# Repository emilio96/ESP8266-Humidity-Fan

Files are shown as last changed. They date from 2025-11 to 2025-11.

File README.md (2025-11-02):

# ESP8266 Smart Fan Controller for Humidity Control

This project is an intelligent fan controller designed to manage air circulation in areas with high humidity, such as behind wardrobes or in damp rooms.

It operates by monitoring ambient temperature and humidity with an **AHTx0 sensor**. Based on these readings, it intelligently controls the speed of a 4-pin PWM computer fan (specifically tested with an ARCTIC F12 PWM) to ensure continuous air movement and prevent moisture buildup.

The system offers two primary interfaces for monitoring and control:
1.  A **Blynk** dashboard for remote access.
2.  A **local Web Server** that provides a clean, modern UI for anyone on the same WiFi network.

## Key Features

* **Humidity-Based Speed Control:** Fan speed is automatically adjusted based on humidity. The fan is off below a minimum threshold (`UMIDITA_MIN`) and scales up as it approaches the maximum threshold (`UMIDITA_MAX`).
***Smart Night Mode:** Automatically reduces the maximum fan speed during specific overnight hours to minimize noise. This requires an active internet connection for NTP time synchronization.
* **Dual Interface (Blynk & Web):**
    * **Blynk Integration:**
        * Sends all key data (Temp, Humidity, RPM, Target Speed, Night Mode) to the Blynk cloud.
        * Uses an efficient `HTTPS batch/update` API call to send all sensor data in one request.
        * Features a `manualOverride` switch on Virtual Pin `V0` to remotely force the fan off.
    * **Local Web Server:**
        * Hosts a responsive HTML/JavaScript webpage on the ESP8266's local IP address.
        * The page provides a real-time dashboard displaying all sensor readings and system status.
        * Includes a toggle button to switch between "Automatic" control and "Manual Override (Off)".
**True RPM Feedback:** Reads the fan's tachometer (TACH) pin to measure and report the *actual* fan speed in RPM.
**Non-Blocking Operation:** Uses `BlynkTimer` to manage all tasks (sensor reads, control logic, data sending, WiFi checks), ensuring the main loop remains responsive.
**25kHz PWM Frequency:** Operates the fan at the standard 25kHz PWM frequency for precise and quiet control.

---

## Hardware & Build

### Required Components

* **Controller:** ESP8266 (e.g., NodeMCU, Wemos D1 Mini).
* **Sensor:** `Adafruit AHTX0` (AHT10 or AHT20) I2C Temperature & Humidity Sensor.
* **Fan:** 1x 4-Pin PWM PC Fan (e.g., ARCTIC F12 PWM).
* **Power Supply:** 12V DC Power Adapter.
* **Voltage Regulator:** `LM7805` 5V linear voltage regulator (and any necessary capacitors).

### Power Setup

The system is designed to run from a single **12V DC power adapter**:
1.  The **12V line** is used to power the fan directly (via its 12V pin).
2.  The **12V line** also feeds the input of an **LM7805 linear voltage regulator**.
3.  The **5V output** from the LM7805 is used to power the ESP8266 (via its `Vin` pin).

### 3D-Printed Enclosure

This repository includes the `.stl` files for a custom 3D-printed enclosure. The case is designed to house the ESP8266, AHTx0 sensor, and the voltage regulator circuit.

---

## Libraries & Dependencies

* `ESP8266WiFi`
* `Adafruit_AHTX0`
* `time.h`
* `WiFiUdp`
* `ESP8266WebServer`
* `BlynkSimpleEsp8266`
* `ESP8266HTTPClient`
* `WiFiClientSecure`

---

## Configuration

Before uploading, you must set the user configuration variables at the top of the code file:

// --- BLYNK ---
#define BLYNK_TEMPLATE_ID ""    // Your blynk template id
#define BLYNK_TEMPLATE_NAME ""  // Your blynk template name
#define BLYNK_AUTH_TOKEN ""     // Your blynk token

// --- WIFI ---
const char* WIFI_SSID = "";     // Your wifi ssid name
const char* WIFI_PASSWORD = ""; // Your wifi password

// --- FAN PINS ---
const int FAN_PWM_PIN = 14;     // Pin D5 on NodeMCU
const int FAN_TACH_PIN = 12;    // Pin D6 on NodeMCU

// --- CONTROL LOGIC ---
const float UMIDITA_MIN = 50.0; // Humidity % to start the fan
const float UMIDITA_MAX = 85.0; // Humidity % to run fan at 100%

// --- NIGHT MODE ---
const int ORA_INIZIO_NOTTE = 23;  // 11:00 PM
const int ORA_FINE_NOTTE = 9;   // 9:00 AM
const int VELOCITA_MAX_NOTTE = 30; // Max speed % during the night

// --- TIMEZONE ---
const char* NTP_SERVER = "pool.ntp.org";
// Find your TZ String here: [https://github.com/nayarsystems/posix_tz_db/blob/master/zones.csv](https://github.com/nayarsystems/posix_tz_db/blob/master/zones.csv)
const char* TZ_INFO = "CET-1CEST,M3.5.0,M10.5.0/3"; // Example for Central Europe

## Blynk Dashboard Setup
The code is pre-configured to send data to specific Virtual Pins. Set up your Blynk dashboard with the following widgets:

V0 (Switch): Power
  Set as a Switch widget.
  Controls the manualOverride. Label it "Power" or "Manual Override".

V1 (Labeled Value): Temperature
  Set as a Labeled Value or Gauge widget.
  Receives var_aht.temp.temperature. Suggested label: %.1f °C.

V2 (Gauge): Humidity
  Set as a Gauge widget (Range 0-100).
  Receives var_aht.humidity.relative_humidity. Suggested label: %.1f %%.

V3 (Gauge): RPM
  Set as a Gauge widget (Range 0-1500, or as needed).
  Receives fanRpm. Suggested label: %.0f RPM.

V4 (Gauge): Target Speed
  Set as a Gauge widget (Range 0-100).
  Receives targetSpeed. Suggested label: %.0f %%.

V5 (LED): NightMode
  Set as an LED widget.
  Receives isNightMode status (1 for ON, 0 for OFF).

Chart (SuperChart):
  Add a SuperChart widget.
  Create datastreams linked to V1 (Temperature) and V2 (Humidity).

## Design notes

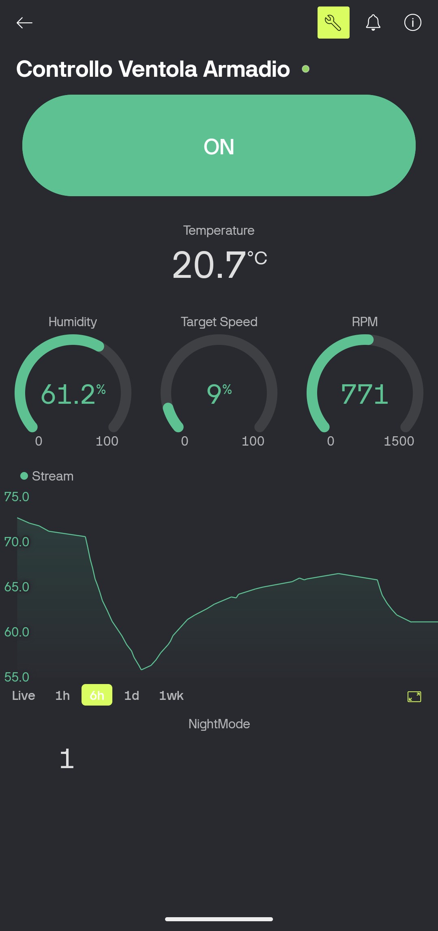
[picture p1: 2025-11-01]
Blynk_dashboard_example.png

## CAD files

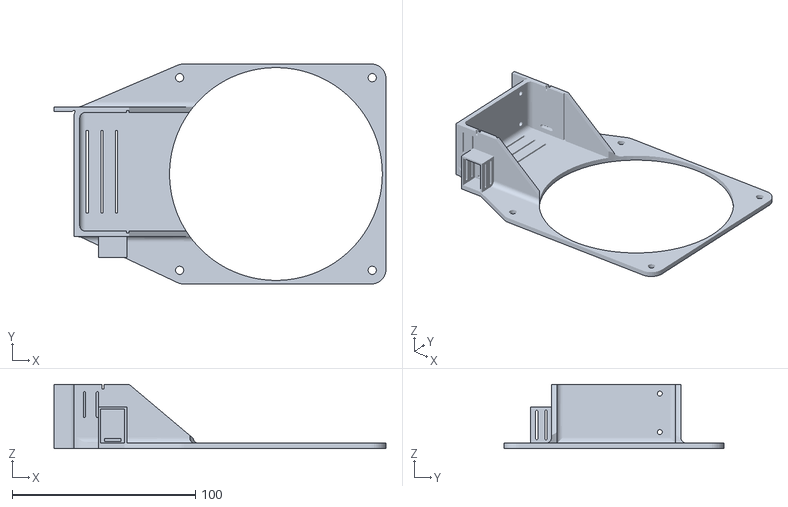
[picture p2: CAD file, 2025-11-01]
3D_files/Montaggio_Ventola_Armadio.stl
181.0 x 120.0 x 35.0

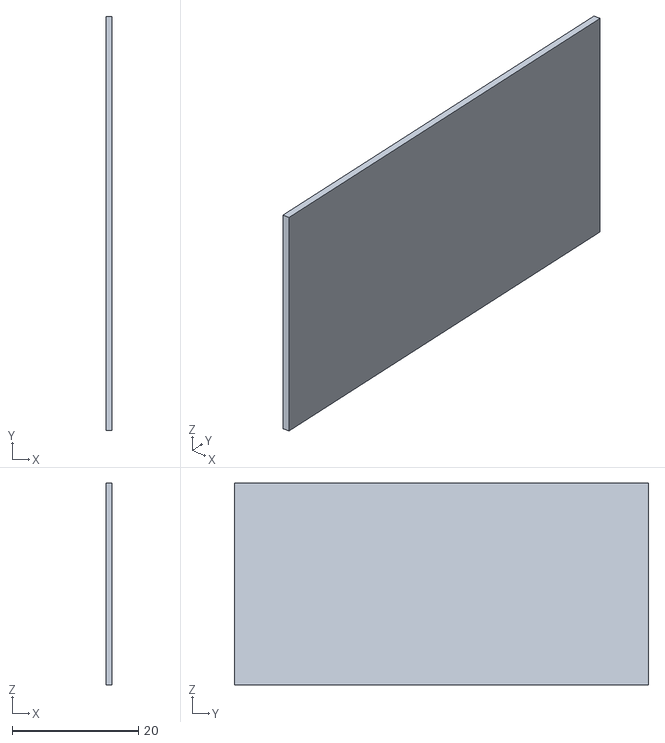
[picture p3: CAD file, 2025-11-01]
3D_files/Chiusura_verticale.stl
1.00 x 65.6 x 32.0

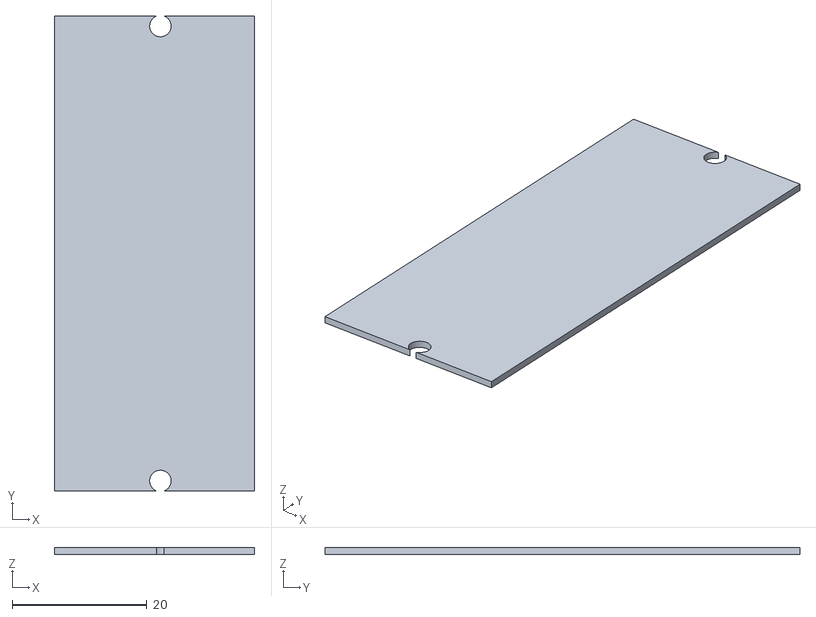
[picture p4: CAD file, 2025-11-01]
3D_files/Chiusura_Orizzontale.stl
29.8 x 70.6 x 1.00

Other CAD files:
3D_files/Chiusura_Orizzontale.CATPart
3D_files/Chiusura_verticale.CATPart
3D_files/Montaggio_Ventola_Armadio.CATPart
3D_files/Product1.CATProduct

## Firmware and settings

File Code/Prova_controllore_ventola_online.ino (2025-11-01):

// %%% The used fan is an ARCTIC F12 PWM %%%

#define BLYNK_TEMPLATE_ID ""    // Your blynk teplate id 
#define BLYNK_TEMPLATE_NAME ""  // Your blynk template name
#define BLYNK_AUTH_TOKEN ""     // Your blynk token
#define BLYNK_PRINT Serial

#include <ESP8266WiFi.h>
#include <Adafruit_AHTX0.h>
#include <time.h>
#include <WiFiUdp.h>
#include <ESP8266WebServer.h>  // NUOVA LIBRERIA PER IL WEB SERVER
#include <BlynkSimpleEsp8266.h>

////////
#include <ESP8266HTTPClient.h>
#include <WiFiClientSecure.h>
////////

// --- CONFIGURAZIONE UTENTE ---
const char* WIFI_SSID = "";     // Your wifi ssid name
const char* WIFI_PASSWORD = ""; // Your wifi password
const int FAN_PWM_PIN = 14;
const int FAN_TACH_PIN = 12;
const float UMIDITA_MIN = 50.0;  //35.0;
const float UMIDITA_MAX = 85.0;
const int PWM_FREQ = 25000;
const int PWM_MAX = 1023 * 0.25;
const int PWM_MIN = 3;
const int ORA_INIZIO_NOTTE = 23;
const int ORA_FINE_NOTTE = 9;
const int VELOCITA_MAX_NOTTE = 30;  //35;
const char* NTP_SERVER = "pool.ntp.org";
const char* TZ_INFO = "CET-1CEST,M3.5.0,M10.5.0/3";

// --- OGGETTO SERVER WEB ---
ESP8266WebServer server(80);  // Crea un'istanza del server sulla porta 80

// --- VARIABILI GLOBALI ---
BlynkTimer timer;
Adafruit_AHTX0 aht;
struct dati_aht10 {
  sensors_event_t humidity, temp;
  unsigned long last_temperature_sync = 0;
} var_aht;
volatile unsigned long tachPulses = 0;
unsigned long lastTachRead = 0;
static unsigned long lastPrint = 0;
float fanRpm = 0.0;
int targetSpeed = 0;
time_t now;
struct tm* timeinfo;
bool isaht = false;
bool isserial = false;
bool istime = false;
bool isNightMode = false;
bool manualOverride = false;  // true = ventola forzata a OFF, false = controllo automatico

float last_sent_temp = -100.0;
float last_sent_hum = -100.0;
float last_sent_rpm = -1.0;
int last_sent_target = -1.0;
bool last_sent_night = false;
bool first_time_sync = false;

// --- FUNZIONI ---

void IRAM_ATTR countPulse() {
  static unsigned long lastMillis = 0;
  if (millis() - lastMillis < 20) { return; }
  tachPulses++;
  lastMillis = millis();
}

BLYNK_WRITE(V0) {
  int value = param.asInt();
  manualOverride = (value == 1);
  if (isserial) Serial.println("Stato override manuale cambiato a: " + String(manualOverride));
}

bool check_before_send() {
  const float temp_threshold = 0.5;
  const float hum_threshold = 0.5;
  const float rpm_threshold = 250;
  const float speed_threshold = 2.5;
  int change_cont = 0;
  if (abs(var_aht.temp.temperature - last_sent_temp) > temp_threshold) change_cont++;
  if (abs(var_aht.humidity.relative_humidity - last_sent_hum) > hum_threshold) change_cont++;
  if (abs(fanRpm - last_sent_rpm) > rpm_threshold) change_cont++;
  if (abs(targetSpeed - last_sent_target) > speed_threshold) change_cont++;
  if (isNightMode != last_sent_night) change_cont++;
  if (change_cont > 0)
    return true;
  else
    return false;
}

// --- FUNZIONE PER INVIARE I DATI A BLYNK TRAMITE HTTPS BATCH ---
void sendBatchToBlynk() {
  //if (WiFi.status() != WL_CONNECTED) return;
  String url = "https://blynk.cloud/external/api/batch/update?token=";
  url += BLYNK_AUTH_TOKEN;
  url += "&v1=" + String(var_aht.temp.temperature, 1);
  url += "&v2=" + String(var_aht.humidity.relative_humidity, 1);
  url += "&v3=" + String(fanRpm, 0);
  url += "&v4=" + String(targetSpeed);
  url += "&v5=" + String(isNightMode ? 1 : 0);

  WiFiClientSecure client;
  client.setInsecure();  // Disabilita verifica certificato (semplice)
  HTTPClient http;

  if (http.begin(client, url)) {
    int code = http.GET();
    String payload = http.getString();
    if (isserial) {
      Serial.print("HTTP code: ");
      Serial.println(code);
      Serial.print("Response: ");
      Serial.println(payload);
    }
    http.end();
  } else {
    if (isserial) Serial.println("Errore inizializzazione HTTPClient");
  }
}

void sendSensorDataToBlynk() {
  if (WiFi.status() != WL_CONNECTED) return;
  bool send = check_before_send();
  if (send) {
    if (Blynk.connected() == false) Blynk.connect(3000);
    //Blynk.virtualWrite(V1, var_aht.temp.temperature, V2, var_aht.humidity.relative_humidity, V3, fanRpm, V4, targetSpeed, V5, isNightMode);
    sendBatchToBlynk();
    last_sent_night = isNightMode;
    last_sent_hum = var_aht.humidity.relative_humidity;
    last_sent_temp = var_aht.temp.temperature;
    last_sent_rpm = fanRpm;
    last_sent_target = targetSpeed;
    if (isserial) Serial.println("Pacchetto dati inviato a Blynk.");
  }
}

void printLocalTime() {
  time(&now);                         // Aggiorna la variabile 'now' con il tempo attuale
  timeinfo = localtime(&now);         // Converte il timestamp in una struttura leggibile

  Serial.print("Data: ");
  Serial.print(timeinfo->tm_mday);    // Giorno del mese (1-31)
  Serial.print("/");
  Serial.print(timeinfo->tm_mon + 1);  // Mese (0-11, quindi aggiungiamo 1)
  Serial.print("/");
  Serial.print(timeinfo->tm_year + 1900);  // Anno (dal 1900, quindi aggiungiamo 1900)

  Serial.print(" | Ora: ");
  Serial.print(timeinfo->tm_hour);  // Ora (0-23)
  Serial.print(":");
  if (timeinfo->tm_min < 10) Serial.print("0");  // Aggiunge lo zero per i minuti < 10
  Serial.print(timeinfo->tm_min);                // Minuti (0-59)
  Serial.print(":");
  if (timeinfo->tm_sec < 10) Serial.print("0");  // Aggiunge lo zero per i secondi < 10
  Serial.println(timeinfo->tm_sec);              // Secondi (0-59)
}


// Funzione #1: Serve la pagina HTML principale (che contiene JavaScript)
void handleRoot() {
  String html = R"rawliteral(
<!DOCTYPE html><html><head><title>Controllo Ventilazione</title>
<style>
  body{font-family: Arial, sans-serif; background-color: #f4f4f4; text-align: center;}
  .container{width: 80%; max-width: 600px; margin: 20px auto; padding: 20px; background: white; border-radius: 8px; box-shadow: 0 2px 4px rgba(0,0,0,0.1);}
  h1{color: #333;} p{font-size: 1.2em; color: #555;} span{font-weight: bold; color: #007BFF;}
  .button{display: inline-block; padding: 10px 20px; margin-top: 20px; font-size: 1em; color: white; border-radius: 5px; text-decoration: none; cursor: pointer;}
  .button-on{background-color: #28a745;} .button-off{background-color: #dc3545;}
</style>
</head><body><div class="container">
  <h1>Stato Sistema di Ventilazione</h1>
  <p>Ora: <span id="time">--</span></p>
  <p>Temperatura: <span id="temp">--</span> &deg;C</p>
  <p>Umidita': <span id="hum">--</span> %</p>
  <p>Velocita' Target: <span id="target">--</span> %</p>
  <p>Velocita' Reale: <span id="rpm">--</span> RPM</p>
  <p>Modalita' Notte: <span id="night">--</span></p>
  <p>Stato Controllo: <span id="status">--</span></p>
  <div id="button-container"></div>
</div>
<script>
function updateData() {
  fetch('/data')
    .then(response => response.json())
    .then(data => {
      document.getElementById('time').innerText = data.time;
      document.getElementById('temp').innerText = data.temp;
      document.getElementById('hum').innerText = data.hum;
      document.getElementById('target').innerText = data.target;
      document.getElementById('rpm').innerText = data.rpm;
      document.getElementById('night').innerText = data.night ? 'ATTIVA' : 'NON ATTIVA';
      
      let statusText = data.override ? 'MANUALE (SPENTO)' : 'AUTOMATICO';
      document.getElementById('status').innerText = statusText;
      
      let btnContainer = document.getElementById('button-container');
      if (data.override) {
        btnContainer.innerHTML = "<a href='/?fan=on' class='button button-on'>Riattiva Controllo Automatico</a>";
      } else {
        btnContainer.innerHTML = "<a href='/?fan=off' class='button button-off'>Forza Spegnimento Ventola</a>";
      }
    });
}
setInterval(updateData, 2000); // Aggiorna i dati ogni 2 secondi
window.onload = updateData; // Aggiorna subito al caricamento della pagina
</script>
</body></html>
)rawliteral";

  // Gestione dei comandi ON/OFF
  if (server.hasArg("fan")) {
    String fanState = server.arg("fan");
    if (fanState == "off") {
      manualOverride = true;
    } else if (fanState == "on") {
      manualOverride = false;
    }
    Blynk.virtualWrite(V0, manualOverride ? 1 : 0);
  }

  server.send(200, "text/html", html);
}

// Serve solo i dati in formato JSON
void handleData() {
  time(&now);
  timeinfo = localtime(&now);
  char timeStr[20];
  sprintf(timeStr, "%02d/%02d/%04d %02d:%02d:%02d", timeinfo->tm_mday, timeinfo->tm_mon + 1, timeinfo->tm_year + 1900, timeinfo->tm_hour, timeinfo->tm_min, timeinfo->tm_sec);

  String json = "{";
  json += "\"time\":\"" + String(timeStr) + "\",";
  json += "\"temp\":" + String(var_aht.temp.temperature) + ",";
  json += "\"hum\":" + String(var_aht.humidity.relative_humidity) + ",";
  json += "\"target\":" + String(targetSpeed) + ",";
  json += "\"rpm\":" + String(fanRpm) + ",";
  json += "\"night\":" + String(isNightMode ? "true" : "false") + ",";
  json += "\"override\":" + String(manualOverride ? "true" : "false");
  json += "}";

  server.send(200, "application/json", json);
}

void fan_rpm() {
  if (millis() - lastTachRead >= 10000) {
    detachInterrupt(digitalPinToInterrupt(FAN_TACH_PIN));
    fanRpm = (tachPulses * 0.1 * 60.0) / 2.0;
    tachPulses = 0;
    lastTachRead = millis();
    attachInterrupt(digitalPinToInterrupt(FAN_TACH_PIN), countPulse, FALLING);
  }
}

void read_sensor_data() {
  if (millis() - var_aht.last_temperature_sync >= 10000) {
    aht.getEvent(&var_aht.humidity, &var_aht.temp);
    var_aht.temp.temperature = round(var_aht.temp.temperature * 10) / 10;
    var_aht.humidity.relative_humidity = round(var_aht.humidity.relative_humidity * 10) / 10;
    var_aht.last_temperature_sync = millis();
  }
}

void target_speed() {
  if (manualOverride) {
    targetSpeed = 0;
    return;
  }
  if (var_aht.humidity.relative_humidity >= UMIDITA_MIN) {
    targetSpeed = map(var_aht.humidity.relative_humidity, UMIDITA_MIN, UMIDITA_MAX, 0, 100);
    targetSpeed = constrain(targetSpeed, 0, 100);
  } else if (var_aht.humidity.relative_humidity < UMIDITA_MIN)
    targetSpeed = 0;
  //Modalità notte
  if (istime) {
    time(&now);                  // Aggiorna la variabile 'now' con il tempo attuale
    timeinfo = localtime(&now);  // Converte il timestamp in una struttura leggibile
    int oraCorrente = timeinfo->tm_hour;
    isNightMode = (oraCorrente >= ORA_INIZIO_NOTTE || oraCorrente < ORA_FINE_NOTTE);
    if (isNightMode) {
      targetSpeed = map(var_aht.humidity.relative_humidity, UMIDITA_MIN, UMIDITA_MAX, 0, VELOCITA_MAX_NOTTE);
      targetSpeed = constrain(targetSpeed, 0, VELOCITA_MAX_NOTTE);
    }
  } else if (!istime && !first_time_sync) {  // Se non ho sincronizzato l'orario nemmeno la prima volta vado a vedlocià basse
    targetSpeed = map(var_aht.humidity.relative_humidity, UMIDITA_MIN, UMIDITA_MAX, 0, VELOCITA_MAX_NOTTE);
    targetSpeed = constrain(targetSpeed, 0, VELOCITA_MAX_NOTTE);
  }
}

void pwm_setting() {
  int pwmValue = map(targetSpeed, 0, 100, 3, PWM_MAX);
  analogWrite(FAN_PWM_PIN, pwmValue);
}

void wifi_check() {
  if (WiFi.status() == WL_CONNECTED && Blynk.connected() == true) {
    return;
  } else if (WiFi.status() == WL_CONNECTED && Blynk.connected() == false) {
    Blynk.connect(3000);
  } else {
    if (isserial) Serial.print("Tentativo riconnessione a WiFi e BLynk ");
    WiFi.mode(WIFI_STA);
    WiFi.begin(WIFI_SSID, WIFI_PASSWORD);
    unsigned long wifiStartTime = millis();
    while (WiFi.status() != WL_CONNECTED && millis() - wifiStartTime < 3000) {
      delay(100);
      if (isserial) Serial.print(".");
    }
    if (WiFi.status() == WL_CONNECTED) Blynk.connect(3000);
    if (Blynk.connected() == true) {
      if (isserial) Serial.println("Connessione riuscita!");
    } else {
      if (isserial) Serial.println("Connessione fallita :( Nuovo tentativo tra 30 min.");
    }
  }
}

void resyncTime() {
  if (WiFi.status() != WL_CONNECTED)
    wifi_check();
  if (WiFi.status() == WL_CONNECTED) {
    configTime(TZ_INFO, NTP_SERVER);
    unsigned long ntp_start_time = millis();
    while (time(nullptr) < 1672531200 && millis() - ntp_start_time < 3000) {
      delay(100);
    }
    if (time(nullptr) > 1672531200) {
      istime = true;
      if (isserial) Serial.println("Orario sincronizzato con successo!");
    } else {
      istime = false;
      if (isserial) Serial.println("Sincronizzazione orario fallita.");
    }
  } else {
    if (isserial) Serial.println("Sincronizzazione orario fallita perchè non connesso al WiFi.");
    istime = false;
  }
}

void report_print() {
  if (isserial) {
    Serial.println("--- REPORT ---");
    // ... (tutta la tua logica di stampa rimane invariata) ...
    if (istime) printLocalTime();
    else Serial.println("Ora: non disponibile");
    Serial.print("Temperatura: ");
    Serial.print(var_aht.temp.temperature);
    Serial.println(" *C");
    Serial.print("Umidita': ");
    Serial.print(var_aht.humidity.relative_humidity);
    Serial.println(" %");
    Serial.print("Velocita' Ventola (Target): ");
    Serial.print(targetSpeed);
    Serial.println(" %");
    Serial.print("Velocita' Ventola (RPM Reali): ");
    Serial.print(fanRpm);
    Serial.println(" RPM");
    Serial.print("Modalita' Notte: ");
    Serial.println(isNightMode ? "ATTIVA" : "NON ATTIVA");
    lastPrint = millis();
  }
}

void run_control() {
  read_sensor_data();
  target_speed();
  pwm_setting();
  if (millis() - lastPrint >= 10000) {
    report_print();
  }
}

void first_update() {
  target_speed();
  pwm_setting();
  //fan_rpm();    //Non viene eseguita perchè non sono passati 10s
  delay(3000);
  sendSensorDataToBlynk();
  //Blynk.virtualWrite(V1, var_aht.temp.temperature, V2, var_aht.humidity.relative_humidity, V3, fanRpm, V4, targetSpeed, V5, isNightMode);
}

void setup() {
  Serial.begin(115200);
  unsigned long start_time = millis();
  while (!Serial && millis() - start_time < 3000) {}
  if (!Serial) isserial = false;
  else isserial = true;
  if (isserial) Serial.println("\n\nAvvio del sistema di controllo ventilazione...");

  if (!aht.begin()) {
    if (isserial) Serial.println("Errore: sensore AHT10 non trovato! Blocco del programma.");
    isaht = false;
  } else {
    isaht = true;
    if (isserial) Serial.println("Sensore AHT10 inizializzato.");
    //Prima lettura
    aht.getEvent(&var_aht.humidity, &var_aht.temp);
    var_aht.temp.temperature = round(var_aht.temp.temperature * 10) / 10;
    var_aht.humidity.relative_humidity = round(var_aht.humidity.relative_humidity * 10) / 10;
  }

  pinMode(FAN_TACH_PIN, INPUT_PULLUP);
  attachInterrupt(digitalPinToInterrupt(FAN_TACH_PIN), countPulse, FALLING);
  analogWriteFreq(PWM_FREQ);
  pinMode(FAN_PWM_PIN, OUTPUT);
  analogWrite(FAN_PWM_PIN, PWM_MIN);
  if (!isaht) analogWrite(FAN_PWM_PIN, 80);
  if (isserial) Serial.println("Controllo ventola inizializzato.");

  if (isserial) Serial.print("Tentativo di connessione a ");
  if (isserial) Serial.println(WIFI_SSID);
  WiFi.mode(WIFI_STA);
  WiFi.begin(WIFI_SSID, WIFI_PASSWORD);
  unsigned long wifiStartTime = millis();
  while (WiFi.status() != WL_CONNECTED && millis() - wifiStartTime < 30000) {
    delay(500);
    if (isserial) Serial.print(".");
  }

  if (WiFi.status() == WL_CONNECTED) {
    if (isserial) Serial.println("\nConnessione WiFi riuscita!");
    if (isserial) Serial.print("Indirizzo IP: ");
    if (isserial) Serial.println(WiFi.localIP());
    // Sincronizzazione dell'ora
    resyncTime();
    if (istime) first_time_sync = true;
    // --- AVVIO DEL SERVER WEB ---
    server.on("/", handleRoot);  // Associa la funzione handleRoot all'indirizzo principale
    server.on("/data", handleData);
    server.begin();  // Avvia il server
    if (isserial) Serial.println("Server HTTP avviato.");
    // Avvio di blynk
    //Blynk.begin(BLYNK_AUTH_TOKEN, WIFI_SSID, WIFI_PASSWORD);
    Blynk.config(BLYNK_AUTH_TOKEN);
    Blynk.connect();
    if (isserial) Serial.println("Sincronizzazione Blynk avviata");
  } else {
    istime = false;
    if (isserial) Serial.println("\nConnessione WiFi fallita! Funzionamento offline.");
  }
  //10000L = 10s. 120000L = 120s = 2m.
  timer.setInterval(120000L, sendSensorDataToBlynk);  // ogni 2 minuti
  timer.setInterval(5000L, run_control);              // ogni 5 secondi
  timer.setInterval(6L * 3600L * 1000L, resyncTime);  // ogni 6 ore
  timer.setInterval(30L * 60L * 1000L, wifi_check);   // ogni 30 minuti
  //Primo calcolo e invio dei parametri
  first_update();
}

void loop() {
  if (WiFi.status() == WL_CONNECTED) {
    server.handleClient();  // Controlla se ci sono client connessi
    if (Blynk.connected()) {
      Blynk.run();  // Mantiene la connessione e gestisce gli eventi di Blynk
    } else {
      Blynk.connect(1000);
      if (Blynk.connected()) Blynk.run();
    }
  }
  fan_rpm();
  timer.run();  // Esegue le funzioni schedulate dal timer
}
